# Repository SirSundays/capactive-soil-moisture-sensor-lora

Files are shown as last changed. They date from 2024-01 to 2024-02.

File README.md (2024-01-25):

# Capactive Soil Moisture Sensor with LoRa

This sensor is a capacitive soil moisture sensor with a completely 3D printable housing, which can send its data over LoRaWAN into the IoT.

## Short Description

Are you interested in a soil moisture and temperature sensor that is suitable for plant pots? If so, you might want to check out my project: the “All in One Capacitive Soil Moisture Sensor w/ LoRa”. This project combines capacitive sensing, LoRaWAN, and 3D printing technologies to create a simple, compact, and efficient sensor. It has a single PCB that serves as both the sensing element and the electronic circuit. A Heltec CubeCell module provides low-power LoRaWAN connectivity to an IoT network. The sensor also measures the actual soil temperature and calibrates the moisture readings for different soil types. A layer of epoxy protects the sensor from various environmental conditions and a rotary device helps to apply it evenly. The sensor is easy to install and use, as it only requires to be inserted into the soil. It also has a good battery life, lasting for several months without replacement.
<p align="center">
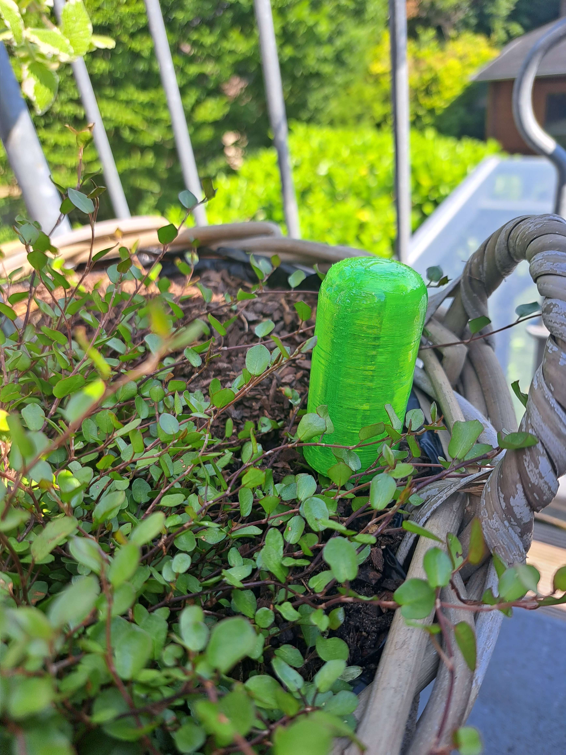
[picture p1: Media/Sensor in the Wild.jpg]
  
</p>

If you want to know more about the project you can read a full explanation on hackaday: [All in One Capacitive Soil Moisture Sensor w/ LoRa](https://hackaday.io/project/194052-all-in-one-capactive-soil-moisture-sensor-w-lora)

## Files
| File Path  | Description  |
| --- |---  |
| 3D-Models/Epoxy | 3D-Data for an epoxy potting jig for the lower half of the housing and a turning device for evenly curing the epoxy when applied to the sensor and housing |
| 3D-Models/Programming | 3D-Data for a simple programming jig to easily program and debug the sensor node |
| 3D-Models/Sensor | 3D-Data for both the standard sensor housing, as well as a split housing with a hole for antenna matching |
| Cap-Test | All Files developed and used to find the optimal values for the circuit parameters for example generated frequency and capacitor and resistor values |
| Code/CapacativeSoilMoisture | Developed code for the Heltec CubeCell AM01 V2. Used with Arduino IDE, Heltec Boards installed. Also depends on OneWire and DallasTemperature library. |
| Code/ttn-minerva-payload-decoder.js | TheThingsNetwork JavaScript Payload decoder to decode the data. |
| Media | All important photos and videos I took while developing and testing the sensor. Just gives an inside on how some of the stuff works (or did not work). |
| PCB/DS18B20Z-Flip-Test | Small PCB, to test out the principle of the temperature chip sensor being flipped so it sits inside the PCB. The uploaded version was the one that worked the best.
| PCB/LoRaSoilMoistureSensor | Final PCB including Gerber Files for ordering at JLCPCB |
| PCB/Sensor-Test | Grove Capactive Soil Moisture Sensor heavily modified to only include the main PCB trace and no electronics, except a header in the top to be able to connect it to a breadboard.

## License
The hardware and associated design files are released under the Creative Commons CC BY-SA 4.0 license. The code is released under the MIT license.

Projects that inspired this project and which partly got worked into this project are:
- b-parasite by rbaron
- Grove - Capacitive Moisture Sensor (Corrosion Resistant) by Seeed Studio

## Disclaimer
This product is not officially LoRaWAN or LoRa certified through the LoRa Alliance. LoRa and LoRaWAN are trademarks of the LoRa Alliance. Heltec states that the module is compatible with the LoRaWAN standard V 1.0.2, but I did not do any verification in that regard.

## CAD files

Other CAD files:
PCB/DS18B20Z-Flip-Test/DS18B20Z-Flip-Test v8.f3z
PCB/LoRaSoilMoistureSensor/CapacitiveSoilMoistureSensor v36.f3z
PCB/Sensor-Test/Grove - Capacitive Moisture Sensor (Corrosion Resistant) v1.f3z

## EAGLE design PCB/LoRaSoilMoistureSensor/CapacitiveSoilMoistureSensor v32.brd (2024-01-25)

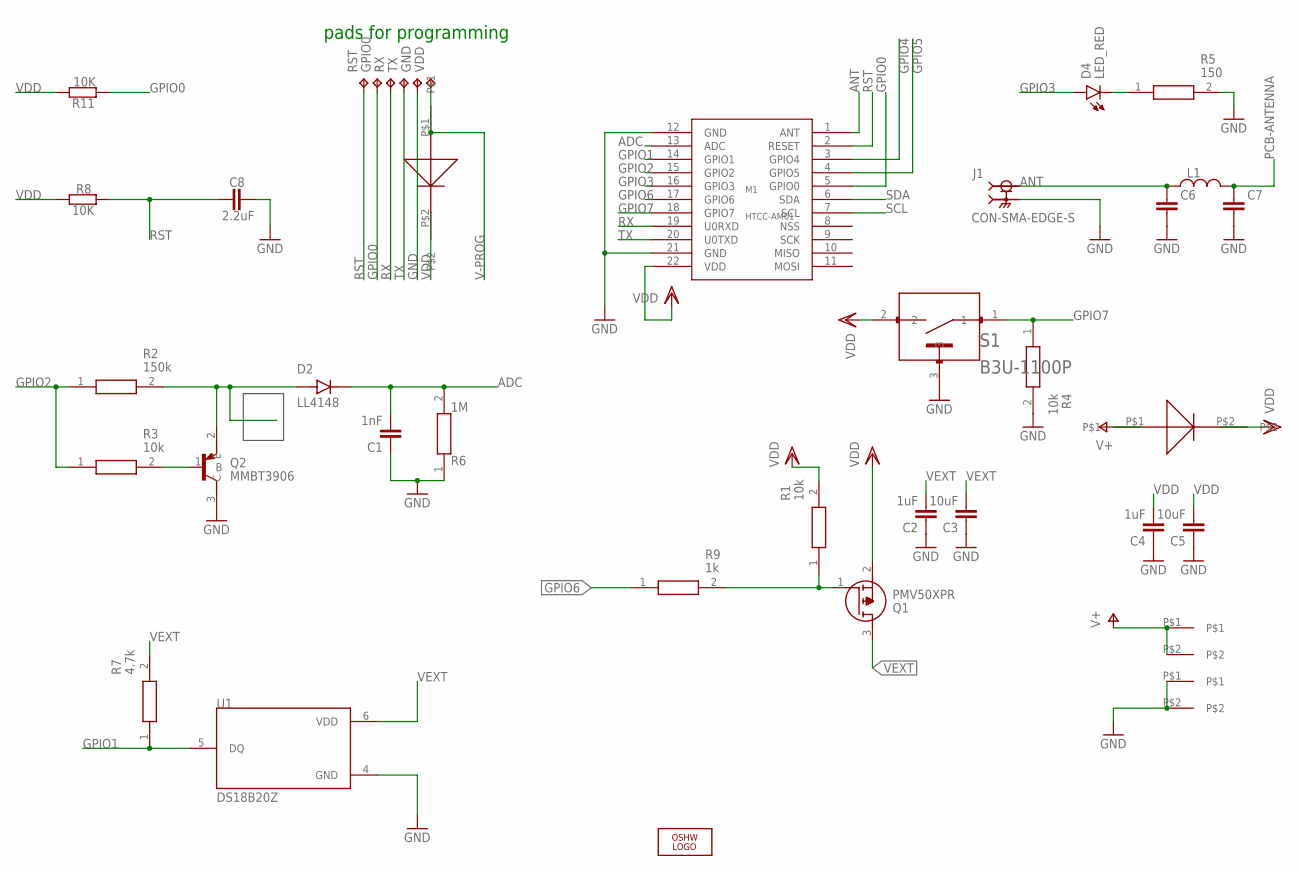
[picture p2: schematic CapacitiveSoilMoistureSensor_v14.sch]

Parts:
C1: 1nF; C0603
C2, C4: 1uF; C0603
C3, C5: 10uF; C0603
C6, C7: C_CHIP-0603(1608-METRIC); CAPC1608X85
C8: 2.2uF; C0603
D1, D3: SOD-323
D2: LL4148; DIO_LL4148
D4: LED_RED; LEDC1608X80N_FLAT-R
GND: TPTP20SQ; TP20SQ
GPIO0: TPTP20SQ; TP20SQ
J1: CON-SMA-EDGE-S; RFSOLUTIONS_CON-SMA-EDGE-S
L1: L_CHIP-0603(1608-METRIC); INDC1608X95N
LOGO1: LOGO-OSHW-FILLX0200-NT; OSHW_FILLX200_NOTEXT
M1: HTCC-AM01
Q1: PMV50XPR; SOT95P230X110-3N
Q2: MMBT3906; SOT95P240X120-3N
R1, R3, R4: 10k; RESC1608X55N
R2: 150k; RESC1608X55N
R5: 150; RESC1608X55N
R6: 1M; RESC1608X55N
R7: 4.7k; RESC1608X55N
R8, R11: 10K; R0603
R9: 1k; RESC1608X55N
RST: TPTP20SQ; TP20SQ
RX: TPTP20SQ; TP20SQ
S1: B3U-1100P; SW_B3U-1100P
TX: TPTP20SQ; TP20SQ
U1: DS18B20Z; SOIC127P600X175-8N
U$3, U$4: KEYSTONE53
VDD: TPTP20SQ; TP20SQ

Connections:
ADC: C1.2, D2.C, M1.13 (ADC), R6.2
ANT: C6.1, J1.1, L1.1, M1.1 (ANT)
GND: C1.1, C2.1, C3.1, C4.1, C5.1, C6.2, C7.2, C8.1, GND.TP, J1.G1 (2), J1.G2 (2), J1.G3 (2), J1.G4 (2), M1.12 (GND), M1.21 (GND), Q2.3 (C), R4.2, R5.2, R6.1, S1.3, U1.4 (GND), U$4.P$1, U$4.P$2
GPIO0: GPIO0.TP, M1.5 (GPIO0), R11.2
GPIO1: M1.14 (GPIO1), R7.1, U1.5 (DQ)
GPIO2: M1.15 (GPIO2), R2.1, R3.1
GPIO3: D4.A, M1.16 (GPIO3)
GPIO4: M1.3 (GPIO4)
GPIO5: M1.4 (GPIO5)
GPIO6: M1.17 (GPIO6), R9.1
GPIO7: M1.18 (GPIO7), R4.1, S1.1
unnamed: Q1.1 (G), R1.1, R9.2
unnamed: Q2.1 (B), R3.2
unnamed: D4.C, R5.1
unnamed: D2.A, Q2.2 (E), R2.2
PCB-ANTENNA: C7.1, L1.2
RST: C8.2, M1.2 (RESET), R8.2, RST.TP
RX: M1.19 (U0RXD), RX.TP
SCL: M1.7 (SCL)
SDA: M1.6 (SDA)
TX: M1.20 (U0TXD), TX.TP
V+: D1.P$1, U$3.P$1, U$3.P$2
V-PROG: D3.P$1, VDD.TP
VDD: C4.2, C5.2, D1.P$2, D3.P$2, M1.22 (VDD), Q1.2 (S), R1.2, R8.1, R11.1, S1.2
VEXT: C2.2, C3.2, Q1.3 (D), R7.2, U1.6 (VDD)

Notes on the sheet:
pads for programming

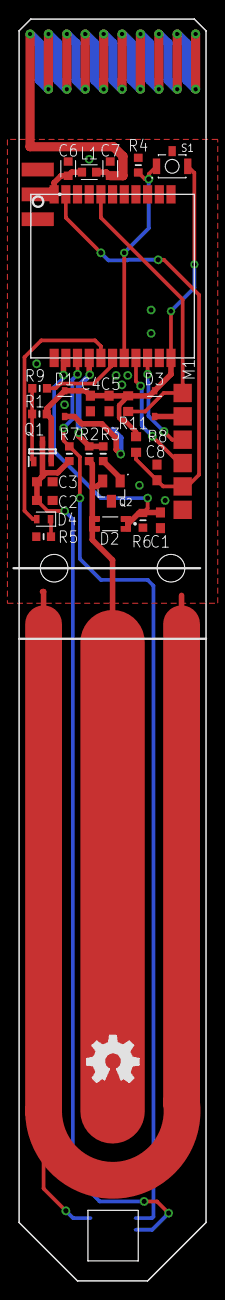
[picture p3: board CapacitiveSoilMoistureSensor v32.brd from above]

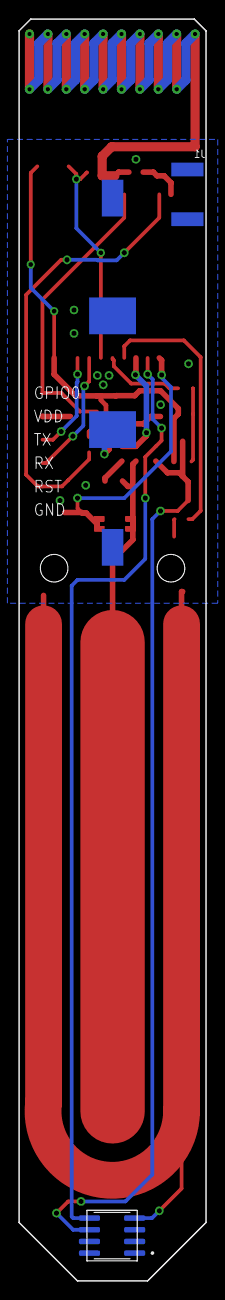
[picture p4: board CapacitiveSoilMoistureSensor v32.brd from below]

Board: 2 copper layers, 20.3 x 137.2 mm, 38 parts (3 on the bottom side), 21 nets.

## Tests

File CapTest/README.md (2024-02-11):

## Files
| File Path  | Description  |
| --- |---  |
| DesignFiles | Capacitvice Soil Moisture PCB but without any electronics - just for hooking it up to a breadboard - modified Grove - Capacitive Moisture Sensor (Corrosion Resistant) by Seeed Studio |
| MeasureCapacitanceArduino | Arduino code for measuring capacitance between 20pf and 1000nf - originally by Anusha on Electronicshub.org - modified to work without an attached display |
| SquareWave-Cubecell | Arduino code specific to the used CubeCell module to generate the desired 53 Mhz square wave signal |
| SquareWave-Nane | Arduino code specific to an Arduino Nano to generate a 62 Mhz square wave signal |
| CapacitorTest-RealValues.circuitjs.txt | Developed circuit to measure the capacitance of the soil moisture pcb. Can also be directly opened via this link in Falstad: Link |
| CapacitorTest-RealityCheck.circuitjs.txt | Developed circuit to measure the capacitance of the soil moisture pcb but this time with the used values of the tested out circuit in real life to check how accurate the simulation actually is. Can also be directly opened via this link in Falstad: Link |

Here is a picture of the developed circuit:
<p align="center">
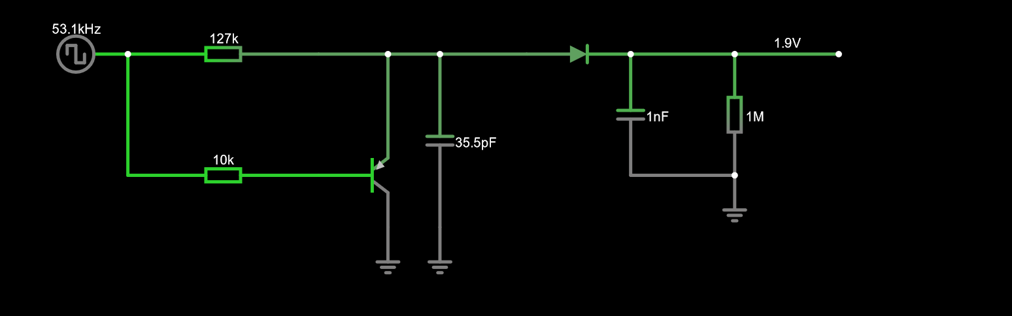
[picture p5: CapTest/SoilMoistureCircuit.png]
  
</p>
                                                                                                                                                                                                                                                                    
This circuit was then built on a breadboard for development and later implemented on a PCB.

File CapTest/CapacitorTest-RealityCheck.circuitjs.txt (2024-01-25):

$ 1 0.000001 18.278915558614752 72 5 50 5e-11
r 608 448 784 448 0 127000
r 608 560 784 560 0 10000
t 784 560 848 560 0 -1 3.299999965863537 2.6292532575957575 200 default
w 784 448 848 448 0
w 848 448 848 544 0
w 608 560 608 448 0
w 848 576 848 608 0
g 848 608 848 640 0 0
w 848 448 896 448 0
d 976 448 1072 448 2 default
c 1072 448 1072 560 0 1e-9 0.5221261341591545 0.001
c 896 448 896 608 0 5e-10 0.6707467082677796 0.001
r 1168 448 1168 560 0 1000000
w 1072 448 1168 448 0
w 1072 560 1168 560 0
g 1168 560 1168 592 0 0
g 896 608 896 640 0 0
w 1168 448 1264 448 2
R 608 448 560 448 0 2 53130 1.65 1.65 0 0.5
w 896 448 976 448 0
o 17 1 0 4098 4.129277371876549 0.0001 0 2 17 3
38 11 F1 0 5e-13 5e-10 -1 Capacitance

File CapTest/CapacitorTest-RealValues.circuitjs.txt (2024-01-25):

$ 1 0.000001 18.278915558614752 72 5 50 5e-11
r 608 448 784 448 0 150000
r 608 560 784 560 0 10000
t 784 560 848 560 0 -1 3.2999999659568604 0.7626041833320807 200 default
w 784 448 848 448 0
w 848 448 848 544 0
w 608 560 608 448 0
w 848 576 848 608 0
g 848 608 848 640 0 0
w 848 448 896 448 0
d 976 448 1072 448 2 default
c 1072 448 1072 560 0 1e-9 2.3882013887510576 0.001
c 896 448 896 608 0 5e-13 2.5373957826247797 0.001
r 1168 448 1168 560 0 1000000
w 1072 448 1168 448 0
w 1072 560 1168 560 0
g 1168 560 1168 592 0 0
g 896 608 896 640 0 0
w 1168 448 1264 448 2
R 608 448 560 448 0 2 50000 1.65 1.65 0 0.5
w 896 448 976 448 0
o 17 1 0 4098 4.129277371876549 0.0001 0 2 17 3
38 11 F1 0 5e-13 5e-10 -1 Capacitance

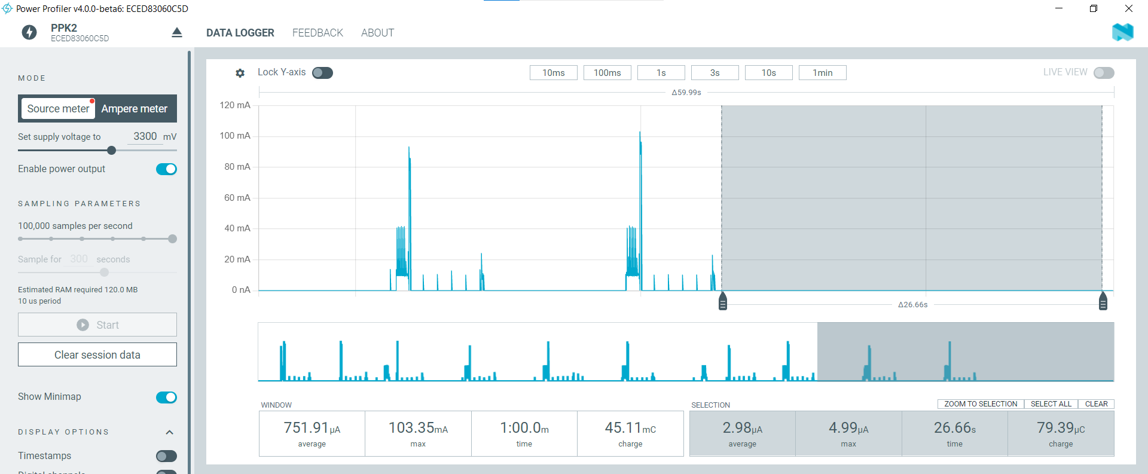
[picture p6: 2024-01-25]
Media/First PCB Tests/DeepSleep Prototype.png

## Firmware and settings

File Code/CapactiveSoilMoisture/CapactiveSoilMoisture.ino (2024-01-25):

#include "LoRaWan_APP.h"
#include "Arduino.h"

#include "PWM1.h"

#include <OneWire.h>
#include <DallasTemperature.h>

#define ONE_WIRE_BUS GPIO1

OneWire oneWire(ONE_WIRE_BUS);
DallasTemperature sensors(&oneWire);

/* OTAA para*/
uint8_t devEui[] = { 0x70, 0xB3, 0xD5, 0x7E, 0xD0, 0x05, 0x99, 0x3F };
uint8_t appEui[] = { 0x00, 0x00, 0x00, 0x00, 0x00, 0x00, 0x00, 0x00 };
uint8_t appKey[] = { 0x68, 0x32, 0x33, 0x5E, 0xD7, 0xAB, 0x97, 0x44, 0xE3, 0x8D, 0x76, 0x68, 0x39, 0xB1, 0xB3, 0x72 };

/* ABP para*/
uint8_t nwkSKey[] = { 0x15, 0xb1, 0xd0, 0xef, 0xa4, 0x63, 0xdf, 0xbe, 0x3d, 0x11, 0x18, 0x1e, 0x1e, 0xc7, 0xda, 0x85 };
uint8_t appSKey[] = { 0xd7, 0x2c, 0x78, 0x75, 0x8c, 0xdc, 0xca, 0xbf, 0x55, 0xee, 0x4a, 0x77, 0x8d, 0x16, 0xef, 0x67 };
uint32_t devAddr = (uint32_t)0x007e6ae1;

/*LoraWan channelsmask, default channels 0-7*/
uint16_t userChannelsMask[6] = { 0xFF00, 0x0000, 0x0000, 0x0000, 0x0000, 0x0000 };

/*LoraWan region, select in arduino IDE tools*/
LoRaMacRegion_t loraWanRegion = ACTIVE_REGION;

/*LoraWan Class, Class A and Class C are supported*/
DeviceClass_t loraWanClass = LORAWAN_CLASS;

/*the application data transmission duty cycle.  value in [ms].*/
uint32_t appTxDutyCycle = 15000;
uint32_t appTxDutyCycleLong = 15 * 60 * 1000;

uint8_t uplinksToLongTx = 8;

/*OTAA or ABP*/
bool overTheAirActivation = LORAWAN_NETMODE;

/*ADR enable*/
bool loraWanAdr = LORAWAN_ADR;

/* set LORAWAN_Net_Reserve ON, the node could save the network info to flash, when node reset not need to join again */
bool keepNet = LORAWAN_NET_RESERVE;

/* Indicates if the node is sending confirmed or unconfirmed messages */
bool isTxConfirmed = LORAWAN_UPLINKMODE;
bool standardIsTxConfirmed = isTxConfirmed;

uint8_t appPort = 1;

/*!
  Number of trials to transmit the frame, if the LoRaMAC layer did not
  receive an acknowledgment. The MAC performs a datarate adaptation,
  according to the LoRaWAN Specification V1.0.2, chapter 18.4, according
  to the following table:

  Transmission nb | Data Rate
  ----------------|-----------
  1 (first)       | DR
  2               | DR
  3               | max(DR-1,0)
  4               | max(DR-1,0)
  5               | max(DR-2,0)
  6               | max(DR-2,0)
  7               | max(DR-3,0)
  8               | max(DR-3,0)

  Note, that if NbTrials is set to 1 or 2, the MAC will not decrease
  the datarate, in case the LoRaMAC layer did not receive an acknowledgment
*/
uint8_t confirmedNbTrials = 4;

// Join Limit can be set to restart the whole MCU when no join is possible. Time in ms
uint32_t join_start = 0;
uint32_t join_limit = 3 * 60 * 1000;

/* Available Settings:
  1. Interval - 32 bit
*/
uint8_t number_settings = 1;

uint8_t uplinks = 0;
bool setupErrorDS = false;

bool commandReturn = false;
uint8_t commandType = 0x00;
uint8_t commandError = 0x00;

uint8_t downlink_uid = 0x00;

/* Prepares the payload of the frame */
static void prepareTxFrame(uint8_t port) {
  // Get Battery Level (Not available on Soil Moisture Sensor)
  uint16_t battery_voltage = 0;

  // Constuct Payload-Header
  appDataSize = 3;
  uint8_t appDataSizeCounter = 3;

  uint16_t power_header = generatePowerHeader(battery_voltage);
  appData[0] = highByte(power_header);
  appData[1] = lowByte(power_header);
  appData[2] = generateMetaInfoHeader();

  if (uplinks == 0) {
    // Common Uplink: Device Info
    appDataSize += 4;
    uint32_t device_info_frame = generateDeviceInfoFrame(1);

    appData[appDataSizeCounter] = uint8_t((device_info_frame & 0xFF000000) >> 24);
    appDataSizeCounter++;
    appData[appDataSizeCounter] = uint8_t((device_info_frame & 0x00FF0000) >> 16);
    appDataSizeCounter++;
    appData[appDataSizeCounter] = uint8_t((device_info_frame & 0x0000FF00) >> 8);
    appDataSizeCounter++;
    appData[appDataSizeCounter] = uint8_t((device_info_frame & 0x000000FF));
    appDataSizeCounter++;

    if (setupErrorDS) {
      appDataSize += 3;

      uint32_t setup_error_frame_DS = generateErrorFrame(0, 1, 1);
      appData[appDataSizeCounter] = uint8_t((setup_error_frame_DS & 0xFF000000) >> 24);
      appDataSizeCounter++;
      appData[appDataSizeCounter] = uint8_t((setup_error_frame_DS & 0x00FF0000) >> 16);
      appDataSizeCounter++;
      appData[appDataSizeCounter] = uint8_t((setup_error_frame_DS & 0x0000FF00) >> 8);
      appDataSizeCounter++;
    }
    
    uplinks++;
  } else {
    if (uplinks < uplinksToLongTx) {
      uplinks++;
    } else if (uplinks == uplinksToLongTx) {
      appTxDutyCycle = appTxDutyCycleLong;
      uplinks++;
    }

    digitalWrite(GPIO6, LOW);
    delay(10);

    sensors.begin();
    delay(40);

    // Data-Frames

    bool measurement_error_ds = 0;

    // Read DS18B20
    int samples = 5;
    float temperatures = 0;

    sensors.requestTemperatures();

    if (sensors.getTempCByIndex(0) != -127) {
      for (int i = 0; i < samples; i++) {
        sensors.requestTemperatures();
        float temperatureTemp = sensors.getTempCByIndex(0);
        temperatures += temperatureTemp;
        delay(2);
      }
    } else {
      measurement_error_ds = 1;
    }
    float temperature = temperatures / samples;

    uint16_t temp100 = temperature * 100;

    digitalWrite(GPIO6, HIGH);

    // Read Soil Moisture
    pwmEnable();
    setPWM_Frequency(PWM_CLK_FREQ_16M);
    setPWM_ComparePeriod(0x12C);
    analogWrite(PWM1, 150);
    delay(100);

    int samples_adc = 10;
    float sm_adcs = 0;

    for (int i = 0; i < samples_adc; i++) {
      uint16_t sm_adcTemp = analogRead(ADC);
      sm_adcs += sm_adcTemp;
      delay(5);
    }

    analogWrite(PWM1, 0);

    uint16_t sm_adc = sm_adcs / samples_adc;

    if (measurement_error_ds) {
      appDataSize += 3;

      uint32_t temperature_error_frame = generateErrorFrame(1, 2, 1);
      appData[appDataSizeCounter] = uint8_t((temperature_error_frame & 0xFF000000) >> 24);
      appDataSizeCounter++;
      appData[appDataSizeCounter] = uint8_t((temperature_error_frame & 0x00FF0000) >> 16);
      appDataSizeCounter++;
      appData[appDataSizeCounter] = uint8_t((temperature_error_frame & 0x0000FF00) >> 8);
      appDataSizeCounter++;
    } else {
      appDataSize += 4;

      uint32_t temperature_frame = generateTemperatureFrame(temp100, 2, 1);
      appData[appDataSizeCounter] = uint8_t((temperature_frame & 0xFF000000) >> 24);
      appDataSizeCounter++;
      appData[appDataSizeCounter] = uint8_t((temperature_frame & 0x00FF0000) >> 16);
      appDataSizeCounter++;
      appData[appDataSizeCounter] = uint8_t((temperature_frame & 0x0000FF00) >> 8);
      appDataSizeCounter++;
      appData[appDataSizeCounter] = uint8_t((temperature_frame & 0x000000FF));
      appDataSizeCounter++;
    }

    appDataSize += 4;

    uint32_t adc_frame = generate16AdcFrame(sm_adc, 2, 2);
    appData[appDataSizeCounter] = uint8_t((adc_frame & 0xFF000000) >> 24);
    appDataSizeCounter++;
    appData[appDataSizeCounter] = uint8_t((adc_frame & 0x00FF0000) >> 16);
    appDataSizeCounter++;
    appData[appDataSizeCounter] = uint8_t((adc_frame & 0x0000FF00) >> 8);
    appDataSizeCounter++;
    appData[appDataSizeCounter] = uint8_t((adc_frame & 0x000000FF));
    appDataSizeCounter++;
  }
}

void pwmEnable()
{
  uint8 enableInterrupts;
  enableInterrupts = CyEnterCriticalSection();
  PWM1_BLOCK_CONTROL_REG |= PWM1_MASK;
  CyExitCriticalSection(enableInterrupts);
  enableInterrupts = CyEnterCriticalSection();
  PWM1_COMMAND_REG = ((uint32)(PWM1_MASK << PWM1_CMD_START));
  CyExitCriticalSection(enableInterrupts);
}

void downLinkDataHandle(McpsIndication_t *mcpsIndication) {
  commandReturn = true;
  commandType = uint8_t(mcpsIndication->Buffer[0]);

  downlink_uid = uint8_t(mcpsIndication->Buffer[1]);

  switch (commandType) {
    case 0:
      {
        // Get Device Info
        prepareTxFrame(appPort);
        LoRaWAN.send();
        break;
      }
    case 1:
      {
        // Restart Device
        prepareTxFrame(appPort);
        LoRaWAN.send();
        delay(30 * 1000);
        HW_Reset(0);
        break;
      }
    case 2:
      {
        // Get Settings
        prepareTxFrame(appPort);
        LoRaWAN.send();
        break;
      }
    case 3:
      {
        // Set Settings
        uint8_t total_settings = 0x00;
        total_settings = uint8_t(mcpsIndication->Buffer[2]);

        uint8_t bufferCounter = 3;

        for (uint8_t i = 0; i < total_settings; i++) {
          uint8_t setting_id = uint8_t(mcpsIndication->Buffer[bufferCounter]);
          bufferCounter++;

          switch (setting_id) {
            // Test 030801000000AFC8 - 45000
            // Interval-Time
            case 0:
              {
                appTxDutyCycle = uint32_t(mcpsIndication->Buffer[bufferCounter]) << 24 | uint32_t(mcpsIndication->Buffer[bufferCounter + 1]) << 16 | uint32_t(mcpsIndication->Buffer[bufferCounter + 2]) << 8 | uint32_t(mcpsIndication->Buffer[bufferCounter + 3]);
                appTxDutyCycleLong = appTxDutyCycle;
                bufferCounter = bufferCounter + 4;
              }
          }
        }

        prepareTxFrame(appPort);
        LoRaWAN.send();
        break;
      }
  }
}

void setup() {
  Serial.begin(115200);
  deviceState = DEVICE_STATE_INIT;
  LoRaWAN.ifskipjoin();

  pinMode(GPIO6, OUTPUT);
  digitalWrite(GPIO6, LOW);
  delay(20);

  sensors.begin();
  sensors.requestTemperatures();

  if (sensors.getTempCByIndex(0) != -127) {
    setupErrorDS = true;
  }
  digitalWrite(GPIO6, HIGH);

  pinMode(GPIO0, ANALOG);
  pinMode(GPIO3, ANALOG);
  pinMode(GPIO4, ANALOG);
  pinMode(GPIO5, ANALOG);

  setPWM_Frequency(PWM_CLK_FREQ_16M);
  setPWM_ComparePeriod(0x12C);

  pinMode(PWM1, OUTPUT);
  pinMode(ADC, ANALOG);
}

void loop() {
  switch (deviceState) {
    case DEVICE_STATE_INIT:
      {
#if (LORAWAN_DEVEUI_AUTO)
        LoRaWAN.generateDeveuiByChipID();
#endif
#if (AT_SUPPORT)
        getDevParam();
#endif
        printDevParam();
        LoRaWAN.init(loraWanClass, loraWanRegion);
        deviceState = DEVICE_STATE_JOIN;
        break;
      }
    case DEVICE_STATE_JOIN:
      {
        join_start = millis();
        LoRaWAN.join();
        break;
      }
    case DEVICE_STATE_SEND:
      {
        join_start = 0;
        prepareTxFrame(appPort);
        LoRaWAN.send();

        deviceState = DEVICE_STATE_CYCLE;
        break;
      }
    case DEVICE_STATE_CYCLE:
      {
        // Schedule next packet transmission
        txDutyCycleTime = appTxDutyCycle + randr(0, APP_TX_DUTYCYCLE_RND);
        LoRaWAN.cycle(txDutyCycleTime);
        deviceState = DEVICE_STATE_SLEEP;
        break;
      }
    case DEVICE_STATE_SLEEP:
      {
        LoRaWAN.sleep();
        break;
      }
    default:
      {
        deviceState = DEVICE_STATE_INIT;
        break;
      }
  }
  // Check for Join Limit
  if (millis() - join_start > join_limit && !IsLoRaMacNetworkJoined) {
    Serial.println("Join Reset");
    delay(50);
    HW_Reset(0);
  }
}

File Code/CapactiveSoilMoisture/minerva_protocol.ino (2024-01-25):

// Type of Power
// 0 - battery power
// 1 - external power
bool type_of_power = 0;
// Type of Powerreading
// 0 - mV
// 1 - mAh
bool type_of_power_reading = 0;

uint8_t protocol_version_major = 0;
uint8_t protocol_version_minor = 1;

uint8_t serialnumber_presence = 0;

uint8_t firmware_version_major = 0;
uint8_t firmware_version_minor = 1;

uint8_t device_type = 3;

uint16_t generatePowerHeader(uint16_t battery_reading) {
  uint16_t header = 0;

  header = type_of_power << 15;
  header = header | type_of_power_reading << 14;

  header = header | battery_reading;

  return header;
}

uint8_t generateMetaInfoHeader() {
  uint8_t header = 0;

  header = protocol_version_major << 4;
  header = header | protocol_version_minor << 1;
  header = header | serialnumber_presence;

  return header;
}

uint16_t generateFrameHeader(uint8_t type, uint8_t event_code, uint8_t sensor) {
  uint16_t header_raw = 0;

  header_raw = type << 8;

  header_raw = header_raw | event_code << 5;

  header_raw = header_raw | sensor;

  return header_raw;
}

uint32_t generateCommandFrame(uint8_t event_code, uint8_t downlink_uid, uint8_t error_code) {
  uint16_t header;
  header = generateFrameHeader(0, event_code, 0);

  uint32_t deviceInfoFrame = 0;
  deviceInfoFrame = uint32_t(header) << 16;

  deviceInfoFrame = deviceInfoFrame | uint32_t(downlink_uid) << 8;

  deviceInfoFrame = deviceInfoFrame | uint32_t(error_code);

  return deviceInfoFrame;
} 

uint32_t generateDeviceInfoFrame(uint8_t event_code) {
  uint16_t header;
  header = generateFrameHeader(1, event_code, 0);

  uint32_t deviceInfoFrame = 0;
  deviceInfoFrame = uint32_t(header) << 16;

  deviceInfoFrame = deviceInfoFrame | uint32_t(firmware_version_major) << 12;
  deviceInfoFrame = deviceInfoFrame | uint32_t(firmware_version_minor) << 8;

  deviceInfoFrame = deviceInfoFrame | uint32_t(device_type);

  return deviceInfoFrame;
} 

uint32_t generateSettingsFrame(uint8_t event_code, uint8_t number_settings) {
  uint16_t header;
  header = generateFrameHeader(2, event_code, 0);

  uint32_t settingsFrame = 0;
  settingsFrame = uint32_t(header) << 16;

  settingsFrame = settingsFrame | uint32_t(downlink_uid) << 8;
  settingsFrame = settingsFrame | uint32_t(number_settings) << 0;

  return settingsFrame;
}

uint64_t generateIntervalSettingsFrame() {
  uint64_t interval_setting_frame = 0;

  interval_setting_frame = 0 << 32;

  interval_setting_frame = interval_setting_frame | uint64_t(appTxDutyCycle);

  return interval_setting_frame;  
}

uint32_t generateErrorFrame(uint8_t error_code, uint8_t event_code, uint8_t sensor) {
  uint32_t header;
  header = generateFrameHeader(3, event_code, sensor);

  uint32_t errorFrame = 0;
  errorFrame = uint32_t(header) << 16;

  errorFrame = errorFrame | (uint32_t(error_code) << 8);

  return errorFrame;
}

uint32_t generateTemperatureFrame(uint16_t temperature, uint8_t event_code, uint8_t sensor) {
  uint32_t header;
  header = generateFrameHeader(4, event_code, sensor);

  uint32_t temperatureFrame = 0;
  temperatureFrame = uint32_t(header) << 16;

  temperatureFrame = temperatureFrame | uint32_t(temperature);

  return temperatureFrame;
}

uint32_t generateHumidityFrame(uint16_t humidity, uint8_t event_code, uint8_t sensor) {
  uint32_t header;
  header = generateFrameHeader(5, event_code, sensor);

  uint32_t humidityFrame = 0;
  humidityFrame = header << 16;

  humidityFrame = humidityFrame | uint32_t(humidity);

  return humidityFrame;
}

uint32_t generateMvFrame(uint16_t mv, uint8_t event_code, uint8_t sensor) {
  uint32_t header;
  header = generateFrameHeader(6, event_code, sensor);

  uint32_t mvFrame = 0;
  mvFrame = header << 16;

  mvFrame = mvFrame | uint32_t(mv);

  return mvFrame;
}

uint32_t generate16AdcFrame(uint16_t adc, uint8_t event_code, uint8_t sensor) {
  uint32_t header;
  header = generateFrameHeader(7, event_code, sensor);

  uint32_t adcFrame = 0;
  adcFrame = header << 16;

  adcFrame = adcFrame | uint32_t(adc);

  return adcFrame;
}
